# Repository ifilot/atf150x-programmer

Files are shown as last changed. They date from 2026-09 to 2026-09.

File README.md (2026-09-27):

# ATF150x programmer





The ATF1502AS and ATF1504AS are 5 V complex programmable logic devices (CPLDs)
used to implement small, persistent digital-logic designs. This project
provides an open-source way to erase, program, and verify these devices. It
combines Arduino Leonardo firmware for the PCB in `pcb/atf150X-programmer`
with a native C++17 CLI for Windows and Linux and a Qt 6 desktop application
for Windows.

The project aims to replace the proprietary ATDH1150USB programming adapter and
its vendor programming software for supported devices. It accepts an existing
JEDEC file, such as one generated by WinCUPL, and transfers it over USB serial
without a vendor programmer, JEDEC converter, Python runtime, or external
serial library. Logic synthesis and JEDEC generation remain separate steps.

## Download

[Download the Windows installer, the Windows and Linux CLI, and the Arduino
Leonardo firmware from GitHub
Releases.](https://github.com/ifilot/atf150x-programmer/releases) Release
packages include documentation, the GPLv3 license, and SHA-256 checksums.

## Desktop application (Windows)

`atf150x-programmer-vX.Y.Z-windows-x86_64-setup.exe` installs **ATF150x
Programmer**, a graphical front end with the same parser, safeguards and
programming algorithm as the CLI. A portable zip with the same contents is
also published.

- **Automatic programmer detection.** The application finds the Arduino
  Leonardo by its USB identity (Arduino LLC `2341` or Arduino SRL `2A03`,
  sketch `8036` or bootloader `0036`), checks the firmware with the `HELLO`
  handshake, and reads the IDCODE of the socketed CPLD.
- **Firmware installation.** The installer bundles the matching Leonardo
  firmware and [AVRDUDE](https://github.com/avrdudes/avrdude). If the Leonardo
  runs another version or another sketch, the application offers to install
  the bundled firmware (a 1200-baud reset into the Caterina bootloader,
  followed by AVRDUDE). The bootloader itself is never modified.
- **Fuse map.** An opened JEDEC file is drawn as a grid of every physical Flash
  cell: one column per programming row, one cell per bit. Cells are colored by
  function (product terms per logic block, macrocell configuration,
  interconnect, global output enables, device configuration and user
  signature). Product terms that compilers disable by connecting every input
  are muted so the terms in use stand out. Hovering over a cell names its row,
  bit, JEDEC fuse and signal, such as `MC3 (pin 6) PT2 · input UIM14
  complement`. The side panel summarizes the device, programmed fuses, product
  terms and macrocells in use, the checksum, and the arming and JTAG settings.
- **Program, verify, erase, identify.** Operations run in the background with
  progress in the status bar and a session log. A JEDEC file that changed on
  disk since it was opened, for example after rebuilding it in WinCUPL, is
  reloaded before programming.
- **Update notification.** On startup (configurable in the Help menu) the
  application checks GitHub for a newer release and shows a download link.

Close the Arduino IDE serial monitor before using the application; the port
cannot be shared.

## Hardware

Supports one **5 V ATF1502AS or ATF1504AS** with JTAG enabled. ATF1502AS uses
IDCODE `0x0150203F`; ATF1504AS uses `0x0150403F`. ASV/BE variants, other
densities, JTAG chains, security locking,
and recovery of JTAG-disabled chips are unsupported.

The pin assignments come from the checked-in PCB:

| JTAG | Leonardo pin | Series resistor |
| --- | --- | --- |
| TDI | D2 | R3 |
| TCK | D3 | R4 |
| TDO | D4 | R5 |
| TMS | D12 | R6 |

This uses GPIO, not the Leonardo's SPI header. The shield's `5V1` pin supplies
its `+5V` net. Fit the chip with the board unpowered, then connect the Leonardo
by USB. Confirm orientation and assembly before the first scan. Firmware leaves
JTAG pins as inputs between sessions and does not control target power.

## Install the Leonardo firmware

Use the Arduino IDE, select **Arduino Leonardo**, and open
`firmware/atf1502_programmer/atf1502_programmer.ino`. Upload normally. There are no
additional Arduino library dependencies.

Alternatively, with Arduino CLI:

```sh
arduino-cli core update-index
arduino-cli core install arduino:avr
arduino-cli board list
arduino-cli compile --fqbn arduino:avr:leonardo firmware/atf1502_programmer
arduino-cli upload --fqbn arduino:avr:leonardo --port /dev/ttyACM0 firmware/atf1502_programmer
```

On Windows use the corresponding `COM` port in the upload command. Uploading
firmware and flashing the CPLD are separate operations. The Leonardo can change
ports while its bootloader is active; use its normal application port for
`atfprog`. Close Serial Monitor before opening the CLI.

## Build the CLI

### Linux

Install a C++17 compiler and CMake 3.16 or newer (for example `build-essential`
and `cmake` on Debian/Ubuntu), then:

```sh
cmake -S . -B build -DCMAKE_BUILD_TYPE=Release
cmake --build build --parallel
ctest --test-dir build --output-on-failure
```

Executable: `build/atfprog`. Serial access uses the operating system's termios
API. If opening `/dev/ttyACM0` returns permission denied, grant your user serial
access according to your distribution (typically membership in `dialout`,
followed by logging out and back in). A stable `/dev/serial/by-id/...` path may
also be used.

### Windows

Install Visual Studio 2022 Build Tools with **Desktop development with C++** and
CMake. In a Developer PowerShell from the repository directory:

```powershell
cmake -S . -B build -A x64
cmake --build build --config Release --parallel
ctest --test-dir build -C Release --output-on-failure
```

Executable: `build\Release\atfprog.exe`. Serial access uses the native Windows
API, including support for ports above `COM9`. MinGW-w64 is also supported; that
build links the C++ runtime statically.

Python 3 is optional for development: CMake enables the Linux PTY integration
test if an interpreter is present. It is not needed to run the CLI.

## Flash a design

Inspect the file and identify the device first:

```sh
build/atfprog inspect path/to/design.jed
build/atfprog scan --port /dev/ttyACM0
build/atfprog flash path/to/design.jed --port /dev/ttyACM0
```

Windows equivalent:

```powershell
.\build\Release\atfprog.exe inspect C:\designs\design.jed
.\build\Release\atfprog.exe scan --port COM3
.\build\Release\atfprog.exe flash C:\designs\design.jed --port COM3
```

Quote paths containing spaces. The port is explicit; `scan` identifies the chip
on that port, rather than enumerating USB devices. `inspect` only reads the file
and never opens a serial port.

`flash` replaces the existing ATF1502AS or ATF1504AS design. It performs these
steps:

1. Parse and validate the JEDEC file, before opening the port.
2. Identify the ATF1502AS and enter programming mode.
3. Erase and blank-check all 212 mapped programming words.
4. Program the image with the arming switch held in its safe state.
5. Read back and compare every mapped bit, including padding, configuration,
   JTAG options and the user signature.
6. If requested by the image, program the arming bit and verify that word.
7. Leave programming mode, enabling the verified design, and release the pins.

Progress and errors go to stderr; results go to stdout. Expect tens of seconds,
not instantaneous flashing. A zero exit status means the requested operation
completed; failures return nonzero. Do not disconnect power during programming.
If interrupted, reconnect and repeat the full `flash` operation.

Additional commands:

```sh
build/atfprog verify path/to/design.jed --port /dev/ttyACM0
build/atfprog erase --port /dev/ttyACM0
build/atfprog --help
build/atfprog --version
```

`verify` reads without erasing or programming. `erase` destroys the current
configuration and checks that all mapped words read as erased. All device
operations briefly stop the CPLD's normal operation while in programming mode.

## Build the desktop application

The GUI is built with MSYS2 MinGW-w64 and Qt 6. Install
[MSYS2](https://www.msys2.org/) and, in a **MSYS2 MINGW64** shell:

```sh
pacman -S --needed mingw-w64-x86_64-{cmake,gcc,ninja,qt6-base,qt6-serialport,qt6-tools} file
gui/packaging/build-dist.sh --package --installer
```

The script compiles the Leonardo firmware with `arduino-cli` when it is on
`PATH` (otherwise pass `--firmware atf1502_programmer.ino.hex`), downloads the
pinned AVRDUDE release, builds and tests everything, and stages a runnable
application with all Qt and MinGW DLLs in `dist/atf150x-programmer`. With
`--package` and `--installer` it also writes the portable zip and, using
[Inno Setup 6](https://jrsoftware.org/isinfo.php), the installer to `dist/`.

For development, configure the whole tree with `-DATF_BUILD_GUI=ON`
(and optionally `-DATF_FIRMWARE_HEX=...`). The fuse-map descriptions in
`gui/resources/fusemap` and the icons are generated by the scripts in
`gui/tools`.

## JEDEC compatibility

`atfprog` accepts ATF1502AS and ATF1504AS JEDEC files produced by tools such
as WinCUPL. It validates the device, checksums, fuse data, and JTAG settings
before opening the serial port. Invalid or unsafe images are rejected before
the CPLD is erased.

See [the protocol documentation](docs/PROTOCOL.md) for supported JEDEC records,
fuse mapping, serial framing, and programming safeguards.

## Troubleshooting

If `scan` returns all zeros or all ones, check the chip supply, orientation,
assembly, JTAG access and firmware pin mapping. This board/software combination
does not provide the high-voltage override needed to recover disabled JTAG.

## Development and references

See [coding style](docs/STYLE.md), [protocol and algorithm](docs/PROTOCOL.md),
[validation details](docs/VALIDATION.md), and
[third-party attribution](docs/THIRD_PARTY.md). CI builds and tests the C++ code
on Linux and Windows, compiles the Arduino sketch, and builds the GUI,
portable package and installer, including a silent install/uninstall test. Matched PLCC-44
[WinCUPL validation designs](examples/logic_test/README.md) are available for
the ATF1502AS and ATF1504AS.

The software, firmware, tests, build configuration and accompanying
documentation are licensed under the GNU General Public License version 3
only (`GPL-3.0-only`); see [LICENSE](LICENSE). Copyright (c) 2026 ATF1502
programmer contributors. Required upstream notices are retained in
[third-party attribution](docs/THIRD_PARTY.md). The existing PCB files retain
their [CC BY-SA 4.0 license](pcb/atf150X-programmer/LICENSE).

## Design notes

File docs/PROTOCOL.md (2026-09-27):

# Firmware protocol and programming algorithm

Version 2 uses USB CDC `Serial` at 115200 baud, 8N1, with DTR asserted. Do not
use 1200 baud: the Leonardo reserves that for bootloader entry. Firmware uses
D2=TDI, D3=TCK, D4=TDO, D12=TMS and portable Arduino GPIO calls with at least
2 microseconds per clock half-cycle. The actual clock speed is lower because of
GPIO call overhead.

## Framing

One command may be outstanding at a time. Lines have these forms:

```text
<sequence> <command and arguments>*<CRC16>\n
<sequence> OK[ <payload>]*<CRC16>\r\n
<sequence> ERR <reason>*<CRC16>\r\n
```

Sequence numbers are decimal 0 through 65535. CRC is four hexadecimal digits
using CRC-16/CCITT-FALSE: polynomial 0x1021, initial value 0xFFFF, no reflection,
and no final XOR. It covers every byte before `*`. Firmware has a 96-byte input
buffer. The host rejects oversized replies, incorrect CRCs, and mismatched
sequences. Sequence values correlate replies; they do not provide
deduplication. The host never automatically retries an erase or write. Invalid
framing or CRC receives no reply and aborts the active programming session.

Row addresses and IDCODE arguments are hexadecimal. Word payloads contain byte
pairs in increasing byte order, least-significant byte first. Within each byte,
bit zero shifts first. Unused high bits in the last byte must be zero. An erased
86-bit word is ten `FF` bytes followed by `3F`; an erased 166-bit word is
twenty `FF` bytes followed by `3F`; an erased JTAG word is `0F`.

| Command | Payload after `OK` | Behavior |
| --- | --- | --- |
| `HELLO` | `ATF15XX 2 v0.3.0` | Reset the session and report protocol and firmware versions |
| `ID` | Eight hexadecimal digits | Reset the TAP, read IDCODE, and release pins |
| `BEGIN <IDCODE>` | None | Require that exact supported IDCODE and enter programming mode |
| `ERASE` | None | Erase the selected supported device; requires an active session |
| `WRITE <row> <hexbytes>` | None | Program one supported-device word; requires an active session |
| `READ <row>` | Word bytes | Read one supported-device word; requires an active session |
| `END` | None | Exit programming mode and release pins |

Error reasons include `DEVICE`, `SESSION`, `ADDRESS`, `LENGTH`, `HEX`,
`PROTECTED`, and `COMMAND`. `BEGIN` compares the requested IDCODE with the
physical device and accepts `0150203F` or `0150403F`. Only mapped addresses
are accepted. A write to row 200 must contain `0F`.

Partial lines time out after one second; sessions time out after five seconds
without a valid command. Long or malformed lines terminate sessions. Firmware
acknowledges commands only after their programming or read delay completes. The
host allows three seconds for a reply and two seconds for writes. If the host
loses contact, the firmware timeout provides eventual cleanup. Cleanup cannot
recover a device whose Flash was partially programmed; repeat the complete
flash operation.

On USB disconnect, malformed framing, or a session timeout, firmware exits
programming mode and releases the driven pins. USB failures are reported to the
user and are not retried automatically. A new connection starts with a fresh
handshake.

## JEDEC parsing and safeguards

The parser accepts STX/ETX-framed files with a design header terminated by `*`,
`QF16808` or `QF34192`, `F0` or `F1`, sparse or multiline `L` records,
and a required `C` fuse checksum. `N`/`NOTE`, `QP`, `QV`, and `J`
metadata are ignored; `G0` is accepted. Test vectors and other unsupported
record types are rejected.

Transmission checksums are verified when nonzero. The standard `0000` trailer
disables that check, as in the supplied WinCUPL examples. Files are read in
binary mode so Windows CRLF bytes remain available for transmission-checksum
validation.

Overlapping or out-of-range fuse data, wrong fuse counts, invalid checksums,
nonzero reserved fuses, and locking requests are rejected. The four
JTAG/security fuses at 16782 through 16785 for ATF1502AS, or 34166 through
34169 for ATF1504AS, must remain `1111`. The host does not silently alter the
final image. An image that leaves its arming switch safe remains safe after
flashing.

## JTAG and fuse packing

The portable `jtag.h` engine handles TAP transitions and waits. The host handles
JEDEC parsing, mapping, erase and blank checking, staging, verification, and
activation. IR is 10 bits and each scan starts and ends in Run-Test/Idle.
Firmware resets with six TMS-high clocks and one TMS-low clock.

The implementation follows Project Bureau's `util/device.py`,
`util/fuseconv.py`, and configuration database at commit
`8b8a97122ec238b6a09868a4bc7def20acef798c`. See the linked upstream sources in
[THIRD_PARTY.md](THIRD_PARTY.md).

| Operation | Sequence |
| --- | --- |
| Identify | IR 059, DR 32-bit IDCODE |
| Enable | IR 280, DR 10-bit 1B9 |
| Disable | IR 280, DR 10-bit 000, reset TAP |
| Erase | IR 2B3, IR 29E, wait 210 ms, IR 2BF |
| Program | IR 2A1, DR 11-bit address, IR 290 OR (address >> 8), DR data, IR 29E, wait 30 ms, IR 2BF |
| Read | IR 2A1, DR 11-bit address, IR 28C, wait 20 ms, IR 290 OR (address >> 8), DR data |

The ATF1502AS has 212 mapped words: rows 0x000 through 0x06B and 0x080
through 0x0E4 contain 86 bits, followed by rows 0x100 (32 bits), 0x200
(4 bits), and 0x300 (16 bits). Six JEDEC fuses 16802 through 16807 are reserved
and must be zero.

The ATF1504AS has 216 mapped words: rows 0x000 through 0x06B and 0x080
through 0x0E8 contain 166 bits, followed by the same three special rows. Six
JEDEC fuses 34186 through 34191 are reserved and must be zero. Unmapped
positions in packed physical rows are initialized to one for both devices.

The upstream prose memory tables have different endpoints from their mapping
code. This implementation uses the mapping code endpoints, covering every
non-reserved fuse without inventing additional rows.

The arming-switch fuse is 16750 on ATF1502AS and 34134 on ATF1504AS. The four
JTAG and protection fuses begin at 16782 and 34166 respectively. Accepted files
must leave all four at one. Staging holds the arming bit at one; after all words
verify, the host writes the final configuration word. Flash programming only
clears bits, so this last write can clear the arming bit. No vendor tool is
invoked at build time or runtime.

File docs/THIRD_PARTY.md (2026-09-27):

# Third-party attribution

The ATF1502AS and ATF1504AS fuse permutations and programming algorithm are
adapted from
[Project Bureau](https://github.com/whitequark/prjbureau), an open-source reverse
engineering project by whitequark. The relevant source snapshot is commit
`8b8a97122ec238b6a09868a4bc7def20acef798c`:

- [Fuse mapping and IDCODE](https://github.com/whitequark/prjbureau/blob/8b8a97122ec238b6a09868a4bc7def20acef798c/util/device.py)
- [Programming sequences](https://github.com/whitequark/prjbureau/blob/8b8a97122ec238b6a09868a4bc7def20acef798c/util/fuseconv.py)
- [Configuration fuse database](https://github.com/whitequark/prjbureau/blob/8b8a97122ec238b6a09868a4bc7def20acef798c/database.json)
- [Programming options and ordering](https://github.com/whitequark/prjbureau/blob/8b8a97122ec238b6a09868a4bc7def20acef798c/docs/options/program.rst)

Adapted portions are in `cli/src/jedec.cc`, `cli/src/programmer.cc`,
`firmware/atf1502_programmer/jtag.h`, `protocol.h`, and the tests. The GUI's
fuse-region descriptions in `gui/resources/fusemap/` are generated from the
configuration fuse database above by `gui/tools/generate_fusemap.py`. The upstream
license notice is retained verbatim below for the upstream portions. The
combined software and project modifications are distributed under
`GPL-3.0-only`; see [LICENSE](../LICENSE). This does not replace the original
upstream notice. The new parser, transport, firmware command protocol and CLI
do not require upstream Python packages at runtime.

```text
Unless otherwise noted, the files in this repository are covered by:

Copyright (C) 2019-2020 whitequark@whitequark.org

Permission to use, copy, modify, and/or distribute this software for
any purpose with or without fee is hereby granted.

THE SOFTWARE IS PROVIDED "AS IS" AND THE AUTHOR DISCLAIMS ALL WARRANTIES
WITH REGARD TO THIS SOFTWARE INCLUDING ALL IMPLIED WARRANTIES OF
MERCHANTABILITY AND FITNESS. IN NO EVENT SHALL THE AUTHOR BE LIABLE FOR
ANY SPECIAL, DIRECT, INDIRECT, OR CONSEQUENTIAL DAMAGES OR ANY DAMAGES
WHATSOEVER RESULTING FROM LOSS OF USE, DATA OR PROFITS, WHETHER IN
AN ACTION OF CONTRACT, NEGLIGENCE OR OTHER TORTIOUS ACTION, ARISING OUT
OF OR IN CONNECTION WITH THE USE OR PERFORMANCE OF THIS SOFTWARE.
```

## AVRDUDE

The Windows GUI package bundles an unmodified
[AVRDUDE 8.2](https://github.com/avrdudes/avrdude/releases/tag/v8.2) binary to
install the Leonardo firmware. AVRDUDE is licensed under the GNU General Public
License version 2 or later. Its license text and the complete corresponding
source archive are installed next to it in `tools/avrdude/`; the build
verifies all three downloads against pinned SHA-256 hashes
(`gui/cmake/Avrdude.cmake`).

## Qt and MinGW runtime

The Windows GUI package includes Qt 6 libraries (LGPL-3.0) and the MinGW-w64
runtime and dependency DLLs from MSYS2, deployed unmodified by `windeployqt6`
and `gui/packaging/deploy-mingw-dependencies.sh`. Their sources are available
from [the Qt Project](https://download.qt.io/) and
[MSYS2](https://packages.msys2.org/).

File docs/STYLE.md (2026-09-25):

# C++ style

Follow the [Google C++ Style Guide](https://google.github.io/styleguide/cppguide.html)
for all firmware, host code and C++ tests. Use clang-format 18 with the
repository's `.clang-format`. The project uses Google-style layout with these
explicit preferences: four-space indentation, four-space continuation indents,
spaces instead of tabs, and class access labels aligned with the class itself.
Control statements use braces, and nonempty function bodies occupy separate
lines. Keep Google's 80-column limit, same-line opening braces and spacing rules.

Comments should explain contracts, ownership, units, ordering and non-obvious
device behavior rather than repeat the implementation.

The code uses:

- `.cc` implementation files and self-contained `.h` headers with project/path
  include guards.
- `UpperCamelCase` functions and types, `snake_case` variables, trailing
  underscores on private class data, and `kUpperCamelCase` constants.
- Project-root include paths, explicit scalar casts, bounded buffers, and
  small helpers for parsing and protocol stages.
- Checked `Status` return values for recoverable errors, without exceptions.
  Output pointers document nullability and failure behavior. Constructors avoid
  I/O; native handles and programming-session cleanup have explicit lifetimes.

## Platform requirements

Keep host code at C++17 and shared firmware headers compatible with the Arduino
AVR toolchain's C++11 mode. The guide explicitly asks projects to consider
portability before adopting newer language features.

Arduino requires `setup()`, `loop()`, `Serial`, and its existing API names and
types. The sketch retains its `.ino` extension, and the test adapter retains
`Arduino.h` and matching framework declarations. Sketch-local includes are
necessary because Arduino copies that directory into a separate build tree.
Tests include the actual sketch to exercise the production handlers. Narrow
`NOLINT` comments mark these framework constraints and required printf argument
types; they are not blanket exclusions of firmware from style checks.

## Check formatting

After configuring CMake with clang-format installed:

```sh
cmake --build build --target format-check
```

To format the source tree from a Linux shell:

```sh
clang-format-18 -i cli/src/*.cc cli/src/*.h tests/*.cc tests/*.h \
  tests/arduino/Arduino.h firmware/atf1502_programmer/*.h \
  firmware/atf1502_programmer/*.ino
```

CI runs the formatting check alongside the Linux, Windows and Arduino builds.
Formatting does not replace review of naming, comments or error handling.

## Function documentation

Use Doxygen block headers for C++ functions, including private helpers and
Arduino callbacks. Use `@brief`, named `@param[in]`, `@param[out]` or
`@param[in,out]` entries, and `@return` for results. Document pointer nullability,
required buffer sizes, ownership, state prerequisites, units and behavior on
failure where applicable. Use `@pre` for caller requirements and `@details`
for additional behavior. Do not add empty parameter/return sections to functions
that have neither. Python test helpers use Doxygen `##` comment headers.

Public declarations carry the complete API contract. Out-of-line definitions
have a short implementation summary; Doxygen combines the declaration and
definition into one documented entry. Keep inline comments for non-obvious
algorithm choices rather than repeating the function header inside its body.
Each source/header has a `@file` overview.

Generate the API reference from the repository root with Doxygen 1.9.8 or newer:

```sh
doxygen Doxyfile
```

Open `build-docs/html/index.html`. XML for documentation audits is generated in
`build-docs/xml`. The configuration includes the Arduino sketch and test code,
checks documented parameter names, and treats documentation warnings as errors.
Generated output is ignored by Git. Doxygen is only needed for documentation;
it is not a firmware or CLI build dependency.

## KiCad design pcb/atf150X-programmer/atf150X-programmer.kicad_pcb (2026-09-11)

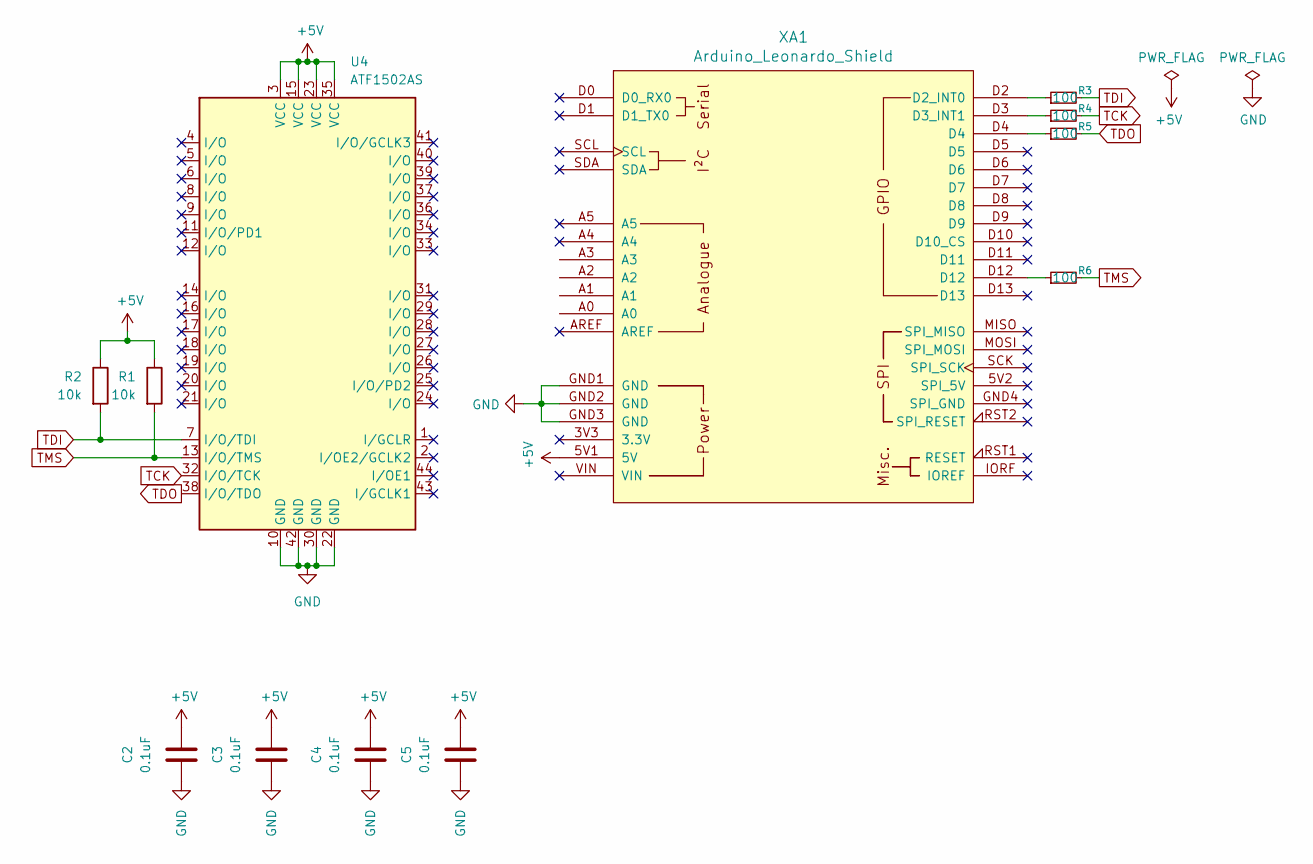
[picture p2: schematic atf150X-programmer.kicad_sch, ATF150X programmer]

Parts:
C2, C3, C4, C5: 0.1uF; C_Disc_D5.0mm_W2.5mm_P5.00mm
R1, R2: 10k; R_Axial_DIN0207_L6.3mm_D2.5mm_P7.62mm_Horizontal
R3, R4, R5, R6: 100; R_Axial_DIN0207_L6.3mm_D2.5mm_P7.62mm_Horizontal
U4: ATF1502AS; PLCC-44_THT-Socket
XA1: Arduino_Leonardo_Shield; Arduino_Uno_Shield

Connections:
+5V: C2.1, C3.1, C4.1, C5.1, R1.1, R2.1, U4.3 (VCC), U4.15 (VCC), U4.23 (VCC), U4.35 (VCC), XA1.5V1 (5V)
GND: C2.2, C3.2, C4.2, C5.2, U4.10 (GND), U4.22 (GND), U4.30 (GND), U4.42 (GND), XA1.GND1 (GND), XA1.GND2 (GND), XA1.GND3 (GND)
unnamed: R5.1, XA1.D4
unnamed: R6.1, XA1.D12
unnamed: R3.1, XA1.D2 (D2_INT0)
unnamed: R4.1, XA1.D3 (D3_INT1)
TCK: R4.2, U4.32 (I/O/TCK)
TDI: R2.2, R3.2, U4.7 (I/O/TDI)
TDO: R5.2, U4.38 (I/O/TDO)
TMS: R1.2, R6.2, U4.13 (I/O/TMS)

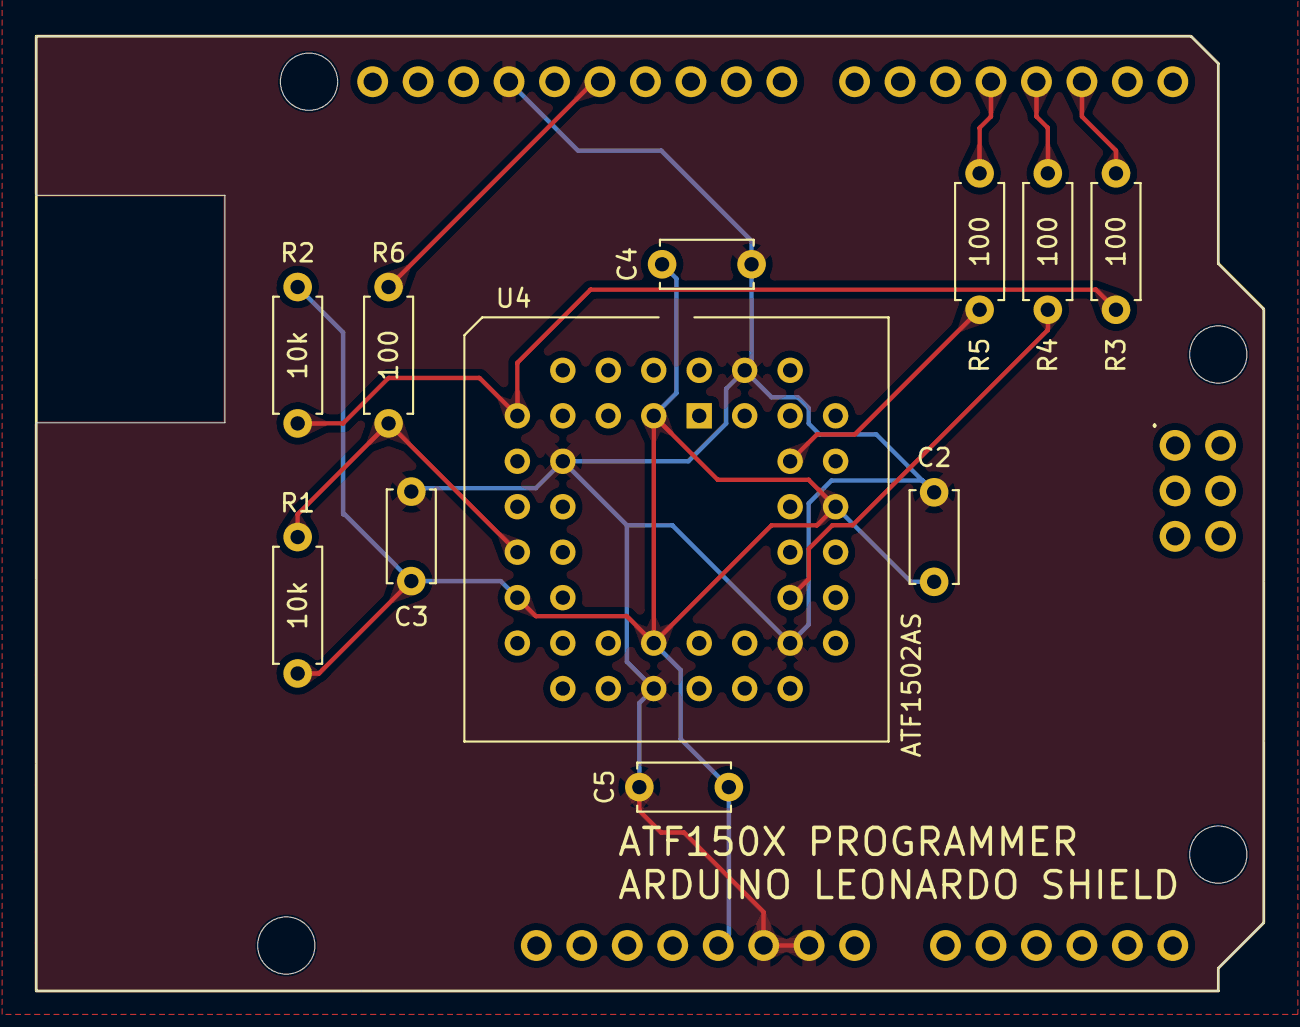
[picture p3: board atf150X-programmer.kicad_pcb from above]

Board: 2 copper layers, 68.6 x 53.3 mm, 12 parts (0 on the bottom side), 10 nets.

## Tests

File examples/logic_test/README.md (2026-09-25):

# ATF1502AS and ATF1504AS logic test

This directory contains matched WinCUPL designs for the 5 V ATF1502AS and
ATF1504AS in PLCC-44 packages. Both designs implement the same four
combinational gates on the same pins. Their JEDEC files provide small,
reproducible images for developing and physically validating device support.

The JTAG pins remain enabled. Do not change the fitter's `JTAG ON` option:
the programmer cannot recover a device whose JTAG interface has been disabled.

## Pin assignments

| Signal | PLCC-44 pin | Direction |
| --- | ---: | --- |
| `A` | 4 | Input |
| `B` | 5 | Input |
| `AND_OUT` | 36 | Output |
| `OR_OUT` | 37 | Output |
| `NAND_OUT` | 39 | Output |
| `NOR_OUT` | 40 | Output |

Pins 7, 13, 32, and 38 remain reserved for TDI, TMS, TCK, and TDO.

Expected output levels are:

| A | B | AND | OR | NAND | NOR |
| ---: | ---: | ---: | ---: | ---: | ---: |
| 0 | 0 | 0 | 0 | 1 | 1 |
| 0 | 1 | 0 | 1 | 1 | 0 |
| 1 | 0 | 0 | 1 | 1 | 0 |
| 1 | 1 | 1 | 1 | 0 | 0 |

## Rebuild with WinCUPL

From a Windows command prompt, run:

```bat
cd examples\logic_test
build.bat
```

The script defaults to `C:\WINCUPL`. Set `CUPL_ROOT` before running it if
WinCUPL is installed elsewhere. It compiles and fits both sources:

- `atf1502as-plcc44.pld` uses `f1502ispplcc44` and `P1502C44`.
- `atf1504as-plcc44.pld` uses `f1504ispplcc44` and `P1504C44`.

The checked-in `.jed` files were generated by Atmel WinCUPL 5.30.4 with the
ATF1502AS/ATF1504AS fitter 1.8.7.8. Intermediate reports remain available
locally after a build but are ignored by Git.

The checked-in images have these identities:

| JEDEC file | Fuse count | Fuse checksum | SHA-256 |
| --- | ---: | ---: | --- |
| `atf1502as-plcc44.jed` | 16,808 | `A5FF` | `665cbbd528926a261bd20208b81b7e8f1a646bd520f6a287fd2fcb250794845e` |
| `atf1504as-plcc44.jed` | 34,192 | `65A1` | `3b8704efbd7be61734a484e22f91290b992127f66df3eb0dd4d21f233a13f42e` |

WinCUPL writes the generation time into each JEDEC header, so rebuilding can
change the whole-file SHA-256 even when the fuse checksum remains identical.

## Hardware validation

Always disconnect USB before changing the device in the programmer socket.
Confirm the PLCC-44 orientation before reconnecting power.

The v0.2.0 flasher can inspect, flash, and verify either image:

```powershell
atfprog.exe inspect examples\logic_test\atf1502as-plcc44.jed
atfprog.exe flash examples\logic_test\atf1502as-plcc44.jed --port COM3
atfprog.exe verify examples\logic_test\atf1502as-plcc44.jed --port COM3
atfprog.exe inspect examples\logic_test\atf1504as-plcc44.jed
atfprog.exe flash examples\logic_test\atf1504as-plcc44.jed --port COM3
atfprog.exe verify examples\logic_test\atf1504as-plcc44.jed --port COM3
```

Cross-validation can be performed in both directions: write the image with one
programmer, then use the other programmer's verify operation to compare it.

After programming, test the truth table in an application fixture with
5 V-compatible logic. A successful JEDEC readback proves configuration
retention; exercising all four input combinations also checks the programmed
logic and the selected I/O pins.

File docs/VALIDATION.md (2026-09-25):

# Validation

Physical testing covers ATF1502AS and ATF1504AS programming on the assembled
PCB through an Arduino Leonardo and native Windows USB serial. An official
ATDH1150USB programmer independently verified an ATF1502AS image written by this
project. In the reverse direction, this project matched every word of an
ATF1504AS image written by the official programmer. This project then wrote and
independently read back the ATF1504AS test image, which the official programmer
also verified successfully. Application-level truth-table testing and physical
Linux USB operation remain pending.

## Checks completed during implementation

- Native Linux C++17 Release build using GCC.
- Native Windows executable cross-built with MinGW-w64.
- Arduino Leonardo build with Arduino AVR core 1.8.8: 9,362 bytes of program
  storage and 482 bytes of static RAM.
- Both checked-in WinCUPL examples are inspected during CTest: ATF1502AS
  `QF16808` and ATF1504AS `QF34192`.
- Parser tests cover checksums, malformed records, lock configurations, reserved
  fuses, device selection, and all 34,186 mapped ATF1504AS fuse coordinates
  against an inverse coordinate model.
- The JTAG engine is checked against an independent TAP state transition table.
- The actual sketch is compiled into a desktop Arduino stub to test framing,
  CRC handling, command responses, invalid addresses and data, device matching,
  JTAG protection, ATF1504AS erase/write access, partial and overlong frames,
  disconnects, and timeout cleanup.
- Linux PTY integration exercises the real CLI against a simulated programmer.
  It covers erase, program, complete staged verification, and activation for
  both devices, including all 216 ATF1504AS physical words.
- Google-style formatting and Doxygen warning checks pass.

Python is required only for Linux PTY tests. The C++ core and firmware simulation
tests also build on Windows.

## Physical ATF1502AS tests — 2026-09-25

The Leonardo firmware was uploaded through Windows Arduino CLI. The bootloader
appeared on COM4; avrdude verified the upload. The running firmware returned to
COM3 and completed the CRC-protected handshake.

The board reported IDCODE `0x0150203F`. The native MinGW `atfprog.exe` flashed
`p2000m-cpm-coboard.jed`: erase and blank checking passed for all 212 words,
all staged words passed readback, and final activation passed. A separate
verify invocation matched all 212 words. Verification passed again after a USB
power cycle.

The same CPLD was later programmed with the checked-in
`atf1502as-plcc44.jed` example by this project. An official ATDH1150USB
programmer then verified that image successfully, providing independent
cross-tool confirmation of the write path and fuse mapping.

For the reverse comparison, the official programmer wrote
`p2000m-cpm-coboard.jed` to an ATF1502AS. Development firmware v0.2.0 then
identified IDCODE `0x0150203F` and matched all 212 physical words through the
Leonardo's read-only `verify` command.

Tested JEDEC SHA-256 values:

```text
p2000m-cpm-coboard.jed:
abf80f86a1adcbbb0e93fcafdb2af26c866ba0351c2b0b858e342c4a9b176b53

atf1502as-plcc44.jed:
665cbbd528926a261bd20208b81b7e8f1a646bd520f6a287fd2fcb250794845e
```

## Physical ATF1504AS tests — 2026-09-25

An official ATDH1150USB programmer wrote
`examples/logic_test/atf1504as-plcc44.jed` to an ATF1504AS. The unpowered
device was moved to the Leonardo programmer. Development firmware v0.2.0
reported IDCODE `0x0150403F`, and the native Windows CLI parsed the 34,192-fuse
image with checksum `65A1`.

The `verify` command read and matched all 216 physical words and exited
successfully. No erase or write command was issued during this first
official-to-open-source comparison.

Write support was then enabled after the mapping and read path had passed that
comparison. The Leonardo erased and blank-checked all 216 words, programmed
`atf1504as-plcc44.jed`, verified every staged word, and applied the final
arming bit. A separate session again identified IDCODE `0x0150403F` and
matched all 216 words. The official ATDH1150USB programmer subsequently
verified the newly written image successfully, completing the bidirectional
cross-validation.

Tested JEDEC SHA-256:

```text
3b8704efbd7be61734a484e22f91290b992127f66df3eb0dd4d21f233a13f42e
```

## Hardware test procedure

1. Disconnect USB before fitting a CPLD, confirm PLCC-44 orientation, and
   reconnect the Leonardo.
2. Run `scan`. Expect `0150203F` for ATF1502AS or `0150403F` for ATF1504AS.
3. Run `inspect` and then `verify` with the JEDEC file for the fitted device.
4. Run `flash`, then a separate `verify`, and repeat verification after a
   power cycle.
5. Program or verify the same image with an official programmer for independent
   comparison.
6. Exercise the intended logic in an application fixture.
7. Repeat supported operations with native Windows and Linux serial ports.

A failing word reports its hexadecimal address and expected and actual byte
strings. Resolve power, orientation, wiring, and JTAG access before changing
timing or mapping code.

## Style

C++ sources follow the Google C++ layout with four-space indentation, include
guards, explicit scalar casts, and Doxygen API contracts. Recoverable failures
return checked `Status` values; production GCC and MinGW builds disable
exceptions. `cmake --build build --target format-check` checks every C++ source,
header, and sketch with the repository's Google-based clang-format
configuration.

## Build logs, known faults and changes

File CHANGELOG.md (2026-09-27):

# Changelog

All notable changes to this project are documented in this file.

The project follows [Semantic Versioning](https://semver.org/spec/v2.0.0.html).
Versions cover the Arduino firmware and the `atfprog` CLI together; both always
ship with the same version.

## [Unreleased]

### Added

- ATF150x Programmer, a Qt 6 desktop application for Windows with automatic
  Arduino Leonardo detection, firmware version checking and installation of
  the bundled firmware through AVRDUDE, identify, program, verify and erase
  with progress reporting, and GitHub release notifications.
- A fuse map that draws every physical Flash cell of a JEDEC file, colored by
  function using Project Bureau's fuse database, with per-cell descriptions
  and usage statistics.
- A Windows installer and portable package built and smoke-tested in CI and
  attached to releases.

### Changed

- The erase, program, verify and activation flow moved from the CLI into a
  shared library used by both `atfprog` and the GUI. CLI behavior is
  unchanged apart from a separate "Blank checking" progress line.

## [0.2.0] - 2026-09-25

### Added

- Matched ATF1502AS and ATF1504AS PLCC-44 WinCUPL logic-test sources and
  generated JEDEC files for device-support validation.
- ATF1504AS identification, JEDEC parsing, complete fuse mapping, erase, blank
  check, programming, activation, and verification across all 216 physical
  words.
- Bidirectional physical ATF1504AS cross-validation: this project verified an
  image written by an official ATDH1150USB programmer, and that programmer
  verified an image written by this project.

## [0.1.0] - 2026-09-25

### Added

- Arduino Leonardo firmware for driving an ATF1502AS over JTAG.
- Native C++ command-line flasher for Windows and Linux.
- Direct parsing and validation of ATF1502AS JEDEC files without vendor tools.
- Device identification, erase, blank check, program and readback verification.
- Safe staged programming that verifies the image before enabling CPLD outputs.
- CRC-protected and sequence-checked USB serial protocol with bounded buffers
  and session timeouts.
- Automated parser, TAP, firmware-protocol and serial-integration tests.
- GitHub Actions builds for firmware and downloadable Windows/Linux CLI
  artifacts.
- Doxygen API documentation and Google-style formatting checks.
- Physical validation using an Arduino Leonardo and ATF1502AS, including
  verification after a power cycle.

[Unreleased]: https://github.com/ifilot/atf150x-programmer/compare/v0.2.0...HEAD
[0.2.0]: https://github.com/ifilot/atf150x-programmer/compare/v0.1.0...v0.2.0
[0.1.0]: https://github.com/ifilot/atf150x-programmer/releases/tag/v0.1.0

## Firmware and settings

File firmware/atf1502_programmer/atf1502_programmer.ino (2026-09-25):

// SPDX-License-Identifier: GPL-3.0-only
// Copyright (c) 2026 ATF1502 programmer contributors

/**
 * @file
 * @brief Leonardo GPIO backend and bounded ATF15xx command service.
 */
#include <Arduino.h>
#include <stdint.h>
#include <stdio.h>
#include <stdlib.h>
#include <string.h>

// Arduino copies the sketch directory into its build tree.
#include "jtag.h"     // NOLINT(build/include_subdir)
#include "version.h"  // NOLINT(build/include_subdir)
#if !defined(ARDUINO_AVR_LEONARDO)
#error "Select Arduino Leonardo: arduino:avr:leonardo"
#endif
namespace {

constexpr uint8_t kTdiPin = 2;
constexpr uint8_t kTckPin = 3;
constexpr uint8_t kTdoPin = 4;
constexpr uint8_t kTmsPin = 12;

/**
 * @brief Provides the Leonardo GPIO implementation of the JTAG backend.
 */
class Pins {
public:
    /**
     * @brief Generates one TCK pulse and samples TDO while TCK is high.
     *
     * @pre DrivePins() has configured the JTAG output pins.
     *
     * @param[in] tms TAP transition bit to drive before the rising edge.
     * @param[in] tdi Input bit to drive before the rising edge.
     * @return Sampled TDO level; TCK is left low.
     */
    bool Clock(bool tms, bool tdi) {
        digitalWrite(kTckPin, LOW);
        digitalWrite(kTmsPin, tms);
        digitalWrite(kTdiPin, tdi);
        delayMicroseconds(2);
        digitalWrite(kTckPin, HIGH);
        delayMicroseconds(2);
        bool bit = digitalRead(kTdoPin);
        digitalWrite(kTckPin, LOW);
        return bit;
    }

    /**
     * @brief Waits for the device programming or read cycle.
     *
     * @param[in] ms Blocking delay in milliseconds.
     */
    void WaitMilliseconds(unsigned int ms) {
        delay(ms);
    }
};

Pins pins;
atf::Jtag<Pins> jtag(pins);
bool active = false;
atf::Device active_device = atf::Device::kUnknown;
bool driving = false;
bool overflow = false;
// Fixed storage bounds RAM use and lets the parser discard overlong frames.
char line[96];
uint8_t line_length = 0;
uint32_t last_byte = 0;
uint32_t last_command = 0;

/**
 * @brief Exits an active programming session and releases the driven pins.
 *
 * Safe to call repeatedly. Clears active/driving state and leaves the JTAG
 * outputs as inputs; it does not erase or recover a partially written image.
 */
void ReleasePins() {
    if (active) {
        jtag.Disable();
    }
    active = false;
    active_device = atf::Device::kUnknown;
    driving = false;
    pinMode(kTckPin, INPUT);
    pinMode(kTdiPin, INPUT);
    pinMode(kTmsPin, INPUT);
}

/**
 * @brief Enables JTAG GPIO outputs without a spurious TCK edge.
 *
 * Sets output levels before enabling the drivers. Repeated calls are harmless.
 */
void DrivePins() {
    if (driving) {
        return;
    }
    digitalWrite(kTckPin, LOW);
    digitalWrite(kTdiPin, LOW);
    digitalWrite(kTmsPin, HIGH);
    pinMode(kTdoPin, INPUT);
    pinMode(kTckPin, OUTPUT);
    pinMode(kTdiPin, OUTPUT);
    pinMode(kTmsPin, OUTPUT);
    driving = true;
}

/**
 * @brief Sends a sequence-tagged, CRC-protected response over USB serial.
 *
 * @pre The decimal sequence, space and payload fit the 80-byte body buffer.
 * Current handlers only pass short, bounded payloads.
 *
 * @param[in] sequence Request sequence, from zero through 65535.
 * @param[in] payload Non-null, null-terminated OK/ERR response text.
 */
void Reply(unsigned int sequence, const char* payload) {
    char buffer[80];
    snprintf(buffer, sizeof(buffer), "%u %s", sequence, payload);
    uint16_t crc = atf::Crc16(buffer, strlen(buffer));
    Serial.print(buffer);
    Serial.print('*');
    char hex_data[5];
    snprintf(hex_data, sizeof(hex_data), "%04X", crc);
    Serial.println(hex_data);
}

/**
 * @brief Validates and executes one READ or WRITE command.
 *
 * @pre A programming session is active. Invalid addresses, lengths or data
 * abort the session before a programming instruction is issued. WRITE may
 * change Flash contents; READ only reads them.
 *
 * @param[in] sequence Sequence to echo in the response.
 * @param[in] write True for WRITE, false for READ.
 * @param[in] start Non-null, null-terminated address and optional data
 * arguments.
 */
void HandleWord(unsigned int sequence, bool write, char* start) {
    char* end;
    auto address = strtoul(start, &end, 16);
    unsigned int bits =
        address <= 768
            ? atf::WordBits(active_device, static_cast<unsigned int>(address))
            : 0;
    if (end == start || !bits || (!write && *end) || (write && *end != ' ')) {
        ReleasePins();
        Reply(sequence, "ERR ADDRESS");
        return;
    }
    unsigned int bytes = (bits + 7) / 8;
    uint8_t data[21] = {};
    if (write) {
        // Validate the entire word before issuing a programming instruction.
        const char* hex_data = end + 1;
        if (strlen(hex_data) != bytes * 2) {
            ReleasePins();
            Reply(sequence, "ERR LENGTH");
            return;
        }
        for (unsigned int i = 0; i < bytes; ++i) {
            int high_nibble = atf::HexDigit(hex_data[2 * i]);
            int low_nibble = atf::HexDigit(hex_data[2 * i + 1]);
            if (high_nibble < 0 || low_nibble < 0) {
                ReleasePins();
                Reply(sequence, "ERR HEX");
                return;
            }
            data[i] = static_cast<uint8_t>((high_nibble << 4) | low_nibble);
        }
        if ((bits % 8 && (data[bytes - 1] >> (bits % 8))) ||
            (address == 512 && data[0] != 0x0f)) {
            ReleasePins();
            Reply(sequence, "ERR PROTECTED");
            return;
        }
        jtag.Program(static_cast<unsigned int>(address), bits, data);
        Reply(sequence, "OK");
    } else {
        jtag.Read(static_cast<unsigned int>(address), bits, data);
        char buffer[48] = "OK ";
        for (unsigned int i = 0; i < bytes; ++i) {
            size_t offset = 3 + 2 * i;
            snprintf(buffer + offset, sizeof(buffer) - offset, "%02X", data[i]);
        }
        Reply(sequence, buffer);
    }
}

/**
 * @brief Dispatches a validated command and refreshes the session deadline.
 *
 * BEGIN checks the device identity; ERASE, READ and WRITE require an active
 * session. Unknown commands abort the session.
 *
 * @param[in] sequence Validated request sequence.
 * @param[in] command Non-null, null-terminated command without CRC framing.
 */
void Dispatch(unsigned int sequence, char* command) {
    last_command = millis();
    if (!strcmp(command, "HELLO")) {
        ReleasePins();
        char response[32];
        snprintf(response, sizeof(response), "OK ATF15XX %u v%s",
                 atf::kProtocolVersion, atf::kVersion);
        Reply(sequence, response);
        return;
    }
    if (!strcmp(command, "END")) {
        ReleasePins();
        Reply(sequence, "OK");
        return;
    }
    bool identify = !strcmp(command, "ID");
    bool begin = !strncmp(command, "BEGIN ", 6);
    if (identify || begin) {
        uint32_t requested_id = 0;
        if (begin) {
            char* end;
            auto value = strtoul(command + 6, &end, 16);
            requested_id = static_cast<uint32_t>(value);
            if (end == command + 6 || *end ||
                atf::DeviceFromId(requested_id) == atf::Device::kUnknown) {
                ReleasePins();
                Reply(sequence, "ERR DEVICE");
                return;
            }
        }
        ReleasePins();
        DrivePins();
        uint32_t id = jtag.Identify();
        if (identify) {
            char buffer[24];
            // The variadic %lX conversion requires unsigned long even on AVR.
            snprintf(buffer, sizeof(buffer), "OK %08lX",
                     static_cast<unsigned long>(id));  // NOLINT(runtime/int)
            ReleasePins();
            Reply(sequence, buffer);
            return;
        }
        if (id != requested_id) {
            ReleasePins();
            Reply(sequence, "ERR DEVICE");
            return;
        }
        jtag.Enable();
        active_device = atf::DeviceFromId(id);
        active = true;
        Reply(sequence, "OK");
        return;
    }
    if (!active) {
        Reply(sequence, "ERR SESSION");
        return;
    }
    if (!strcmp(command, "ERASE")) {
        jtag.Erase();
        Reply(sequence, "OK");
        return;
    }
    bool write = strncmp(command, "WRITE ", 6) == 0;
    if (write || strncmp(command, "READ ", 5) == 0) {
        HandleWord(sequence, write, command + (write ? 6 : 5));
        return;
    }
    ReleasePins();
    Reply(sequence, "ERR COMMAND");
}

/**
 * @brief Validates and dispatches the complete frame in the shared line buffer.
 *
 * @pre line contains a null-terminated frame without CR/LF.
 * Replaces the star delimiter with a null terminator. Invalid framing or CRC
 * aborts the session without a reply; the host then observes a receive timeout.
 */
void Execute() {
    char* star = strchr(line, '*');
    if (!star || strlen(star + 1) != 4) {
        ReleasePins();
        return;
    }
    unsigned int crc = 0;
    for (unsigned int i = 1; i <= 4; ++i) {
        int h = atf::HexDigit(star[i]);
        if (h < 0) {
            ReleasePins();
            return;
        }
        crc = (crc << 4) | static_cast<unsigned int>(h);
    }
    if (crc != atf::Crc16(line, static_cast<size_t>(star - line))) {
        ReleasePins();
        return;
    }
    *star = 0;
    char* end;
    auto sequence = strtoul(line, &end, 10);
    if (end == line || *end != ' ' || sequence > 65535) {
        ReleasePins();
        return;
    }
    Dispatch(static_cast<unsigned int>(sequence), end + 1);
}

}  // namespace

/**
 * @brief Initializes USB serial and leaves the JTAG pins undriven.
 *
 * Arduino calls this once at startup. The entry-point name is
 * framework-defined.
 */
void setup() {
    pinMode(kTdoPin, INPUT);
    ReleasePins();
    Serial.begin(115200);
}

/**
 * @brief Services bounded serial frames and expires abandoned sessions.
 *
 * Arduino calls this repeatedly. Disconnects, partial-frame timeout and
 * session timeout release the pins. Unsigned deadline subtraction handles
 * millis() wraparound on the Leonardo.
 */
void loop() {
    if (!Serial && driving) {
        ReleasePins();
    }
    if ((line_length || overflow) && millis() - last_byte > 1000) {
        line_length = 0;
        overflow = false;
        ReleasePins();
    }
    if (active && millis() - last_command > 5000) {
        ReleasePins();
    }
    while (Serial.available()) {
        char c = static_cast<char>(Serial.read());
        last_byte = millis();
        if (c == '\r') {
            continue;
        }
        if (c == '\n') {
            if (!overflow) {
                line[line_length] = 0;
                Execute();
            } else {
                ReleasePins();
            }
            line_length = 0;
            overflow = false;
        } else if (line_length < sizeof(line) - 1 && !overflow) {
            line[line_length++] = c;
        } else {
            overflow = true;
        }
    }
}

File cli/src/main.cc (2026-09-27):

// SPDX-License-Identifier: GPL-3.0-only
// Copyright (c) 2026 ATF1502 programmer contributors

/**
 * @file
 * @brief CLI argument handling and console reporting for programmer flows.
 */
#include <iostream>
#include <string>

#include "cli/src/jedec.h"
#include "cli/src/programmer.h"
#include "cli/src/serial.h"
#include "cli/src/status.h"
#include "firmware/atf1502_programmer/protocol.h"
#include "firmware/atf1502_programmer/version.h"

namespace atf {
namespace {

/**
 * @brief Prints stage progress to stderr on a single rewritten line.
 *
 * Word-level stages update every 16 words and finish with a newline.
 *
 * @param[in] stage Current operation phase.
 * @param[in] done Completed words within the stage.
 * @param[in] total Total words within the stage.
 */
void PrintProgress(Stage stage, unsigned int done, unsigned int total) {
    if (stage == Stage::kErasing || stage == Stage::kActivating) {
        if (done == 0) {
            std::cerr << StageName(stage) << "...\n";
        }
        return;
    }
    if (done == 0) {
        return;
    }
    if (done % 16 == 0 || done == total) {
        std::cerr << '\r' << StageName(stage) << ' ' << done << '/' << total
                  << std::flush;
    }
    if (done == total) {
        std::cerr << '\n';
    }
}

/**
 * @brief Writes command syntax and erase behavior to stdout.
 */
void PrintUsage() {
    std::cout << "ATF1502AS/ATF1504AS programmer v" << kVersion << "\n"
              << "  atfprog inspect FILE.jed\n"
              << "  atfprog scan --port PORT\n"
              << "  atfprog erase --port PORT\n"
              << "  atfprog flash FILE.jed --port PORT\n"
              << "  atfprog verify FILE.jed --port PORT\n"
              << "  atfprog --version\n"
              << "PORT: /dev/ttyACM0 (Linux), COM3 (Windows)\n"
              << "flash erases, programs and verifies; erase destroys the "
                 "existing design.\n";
}

/**
 * @brief Validates arguments and executes one CLI operation.
 *
 * Validates JEDEC data before opening the port. After BEGIN succeeds, attempts
 * END even when the operation fails, preserving the original diagnostic.
 *
 * @param[in] argc Argument count, at least two.
 * @param[in] argv Non-null array of argc non-null argument strings.
 * @return Success or the first argument, file, device or operation error.
 */
Status Run(int argc, char** argv) {
    std::string action = argv[1];
    std::string file;
    std::string port;
    bool needs_file =
        action == "inspect" || action == "flash" || action == "verify";
    if (!needs_file && action != "scan" && action != "erase") {
        return Status("Unknown command: " + action);
    }
    for (int i = 2; i < argc; ++i) {
        std::string argument = argv[i];
        if (argument == "--port" && i + 1 < argc && port.empty()) {
            port = argv[++i];
        } else if (needs_file && file.empty() && argument.rfind("-", 0) != 0) {
            file = argument;
        } else {
            return Status("Unexpected argument: " + argument);
        }
    }
    if (needs_file && file.empty()) {
        return Status("A JEDEC filename is required");
    }
    if (action == "inspect" && !port.empty()) {
        return Status("inspect does not use a serial port");
    }
    JedecFile jedec;
    Image image;
    if (needs_file) {
        // Validate before opening the port, so bad files cannot erase a device.
        std::string text;
        Status status = ReadFile(file, &text);
        if (!status.ok()) {
            return status;
        }
        status = ParseJedec(text, &jedec);
        if (!status.ok()) {
            return status;
        }
        image = PackFuses(jedec.device, jedec.fuses);
        std::cout << DeviceName(jedec.device) << ": " << FuseCount(jedec.device)
                  << " fuses, " << image.size()
                  << " programming words; fuse checksum valid; JTAG enabled, "
                     "read protection off.\n";
        if (jedec.fuses[ArmingFuse(jedec.device)]) {
            std::cout << "Image leaves CPLD outputs disabled (arming switch is "
                         "safe).\n";
        }
    }
    if (action == "inspect") {
        return Status();
    }
    if (port.empty()) {
        return Status("Select a serial port using --port PORT");
    }
    Connection connection;
    Status status = connection.Open(port);
    if (!status.ok()) {
        return status;
    }
    std::string id;
    status = connection.Command("ID", &id);
    if (!status.ok()) {
        return status;
    }
    std::cout << "IDCODE: 0x" << id << '\n';
    Device device = DeviceFromIdText(id);
    if (device == Device::kUnknown) {
        return Status("Unsupported ATF15xx IDCODE " + id);
    }
    if (action == "scan") {
        std::cout << "Device: " << DeviceName(device) << '\n';
        return Status();
    }
    if (needs_file && jedec.device != device) {
        return Status(std::string("JEDEC targets ") + DeviceName(jedec.device) +
                      ", but connected device is " + DeviceName(device));
    }
    Operation operation = action == "erase"   ? Operation::kErase
                          : action == "flash" ? Operation::kFlash
                                              : Operation::kVerify;
    status = RunSession(connection, operation, device, image, PrintProgress);
    if (!status.ok()) {
        return status;
    }
    std::cout << (action == "erase"   ? "Erase and blank check complete.\n"
                  : action == "flash" ? "Flash and verification complete.\n"
                                      : "Verification complete.\n");
    return Status();
}

}  // namespace
}  // namespace atf

/**
 * @brief Dispatches the CLI and translates status into a process exit code.
 *
 * @param[in] argc Process argument count.
 * @param[in] argv Process argument strings.
 * @return Zero on success/help, one on failure, or two if no command was given.
 */
int main(int argc, char** argv) {
    if (argc < 2) {
        atf::PrintUsage();
        return 2;
    }
    if (argc == 2 &&
        (std::string(argv[1]) == "--help" || std::string(argv[1]) == "-h")) {
        atf::PrintUsage();
        return 0;
    }
    if (argc == 2 && std::string(argv[1]) == "--version") {
        std::cout << "atfprog v" << atf::kVersion << '\n';
        return 0;
    }
    atf::Status status = atf::Run(argc, argv);
    if (!status.ok()) {
        std::cerr << "\nError: " << status.message() << '\n';
        return 1;
    }
    return 0;
}

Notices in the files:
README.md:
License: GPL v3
